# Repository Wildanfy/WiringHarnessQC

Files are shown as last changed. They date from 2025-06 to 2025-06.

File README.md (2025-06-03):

**README.md**

---

## QC Cable Tester Berbasis ESP32 + Bluetooth

**Deskripsi Singkat**
Proyek ini adalah implementasi sistem Quality Control (QC) untuk pengujian konektivitas kabel, menggunakan modul ESP32, rangkaian shift register 80/88-bit, multiplexer (MUX) hingga 6 buah, dan koneksi Bluetooth. Dengan satu rangkaian, Anda dapat memeriksa hingga 76 kanal “normal” dan 8 kanal “X” secara otomatis. Hasil QC (terhubung, putus, short, salah jalur) kemudian dikirim melalui USB Serial dan Bluetooth Serial secara bersamaan dalam format teks.

---

## Daftar Isi

1. [Fitur Utama](#fitur-utama)
2. [Persyaratan Hardware](#persyaratan-hardware)
3. [Skema Pin dan Konektivitas](#skema-pin-dan-konektivitas)
4. [Persiapan Perangkat Lunak](#persiapan-perangkat-lunak)
5. [Cara Mengunggah (Upload) ke ESP32](#cara-mengunggah-upload-ke-esp32)
6. [Perintah Bluetooth / USB Serial](#perintah-bluetooth--usb-serial)
7. [Penjelasan Fungsi-Fungsi Utama](#penjelasan-fungsi-fungsi-utama)
8. [Format Output QC](#format-output-qc)

---

## Fitur Utama

* **Pengujian 76 Kanal Normal**

  * Memanfaatkan 5 buah MUX 16:1 untuk membaca kondisi setiap pin kabel di kanal 1–76.
  * Deteksi otomatis:

    * `C` (Connected)
    * `N` (Disconnected)
    * `S&<nomor partner>` (Short dengan kanal lain)
    * `W&<nomor partner>` (Miswire / salah jalur)
  * Penanganan kondisi khusus (edge-case) pada grup K2 dan K3 sesuai skema QC kabel di dokumentasi.
* **Pengujian 8 Kanal “X” (MUX6)**

  * Rangkaian tambahan untuk kabel tipe “X” (kanal 80–87) menggunakan MUX6.
  * Deteksi antar-MUX: apabila kanal X terhubung / short / miswire ke salah satu dari 88 global bit (76 kanal normal + 8 X).
* **Bluetooth Serial + USB Serial**

  * Nama perangkat Bluetooth: **“QC Cable”**
  * Hasil pengukuran QC langsung dikirim ke kedua antarmuka (Serial USB & Bluetooth).
  * Komunikasi satu arah (ESP32 → PC / Handphone) untuk log hasil QC.
* **Mode QC Fleksibel**

  * `start` : hanya QC kabel normal (1–76)
  * `startx`: hanya QC kabel X (80–87)
  * `startall`: QC semua secara bersamaan (1–76 dan 80–87)
  * `stop` : menghentikan pengukuran QC dan mereset pin

---

## Persyaratan Hardware

1. **ESP32** (atau varian serupa dengan fitur BluetoothClassic)
2. **Shift Register 80-bit / 88-bit**

   * Anda dapat menyusun rangkaian shift register (misalnya menggunakan beberapa IC 74HC595 beruntun) untuk total 80 bit.
   * Untuk skema kabel “X” (8 kanal tambahan), gunakan shift register hingga 88 bit.
3. **Multiplexer (MUX)**

   * 5 buah MUX 16:1 (misal CD74HC4067 atau sejenis). Masing-masing MUX menangani 16 bit sinyal dari shift register untuk 76 kanal normal (5×16 = 80, gunakan 76).
   * 1 buah MUX 16:1 untuk kabel “X” (kanal 80–87).
4. **Kabel Jumper / Breadboard**
5. **Catu Daya 5V (untuk MUX & Shift Register)**
6. **Kabel Uji / Fixture**

   * Sambungkan kabel-kabel yang akan diuji ke pin output shift register / MUX sesuai diagram.
7. **Komputer / Smartphone**

   * Untuk menerima data QC via USB Serial atau Bluetooth Serial.

---

## Skema Pin dan Konektivitas

```
ESP32                              Shift Register / MUX / Fixture
--------------------------------------------------------------------------------
GPIO 23   (DS)      → Data (SER) pada shift register
GPIO 18   (SHCP)    → Clock (SRCLK) pada shift register
GPIO 5    (STCP)    → Latch (RCLK) pada shift register

GPIO 26   (SIG)     ← Output “sense” (hasil pembacaan) dari MUX (digitalRead)
GPIO 13   (S0)      → Select bit 0 pada semua MUX (S0)
GPIO 12   (S1)      → Select bit 1 pada semua MUX (S1)
GPIO 14   (S2)      → Select bit 2 pada semua MUX (S2)
GPIO 19   (S3)      → Select bit 3 pada semua MUX (S3)

GPIO 25   (EN_MUX1) → Enable MUX1 (untuk kanal 1–16)
GPIO 33   (EN_MUX2) → Enable MUX2 (untuk kanal 17–32)
GPIO 15   (EN_MUX3) → Enable MUX3 (untuk kanal 33–48)
GPIO 2    (EN_MUX4) → Enable MUX4 (untuk kanal 49–64)
GPIO 4    (EN_MUX5) → Enable MUX5 (untuk kanal 65–80)

GPIO 27   (EN_MUX6) → Enable MUX6 (untuk kabel X, kanal 80–87)
```

* **Catatan Channel Mapping**

  * Kanall 1–13 → `K1-A1` … `K1-A13`
  * Kanall 14–26 → `K1-B1` … `K1-B13`
  * Kanall 27–39 → `K2-A1` … `K2-A13`
  * Kanall 40–52 → `K2-B1` … `K2-B13`
  * Kanall 53–64 → `K3-A1` … `K3-A12`
  * Kanall 65–76 → `K3-B1` … `K3-B12`
  * Kabel “X” (8 kanal) → `X-1` … `X-8`

---

## Persiapan Perangkat Lunak

1. **Install Arduino IDE (versi terbaru disarankan)**

   * Bisa diunduh di [https://www.arduino.cc/en/software](https://www.arduino.cc/en/software) (sesuaikan OS)
2. **Tambahkan Board ESP32 ke Arduino IDE**

   * Buka **File → Preferences**
   * Tambahkan URL berikut ke `Additional Boards Manager URLs`:

     ```
     https://raw.githubusercontent.com/espressif/arduino-esp32/gh-pages/package_esp32_index.json
     ```
   * Buka **Tools → Board → Boards Manager**, cari “esp32” lalu install “esp32 by Espressif Systems”.
3. **Library yang Diperlukan**

   * `BluetoothSerial.h` (sudah tersedia saat menginstal board ESP32)
   * Tidak ada library eksternal lain (semua fungsi shift register dan multiplexer ditulis manual).

---

## Cara Mengunggah (Upload) ke ESP32

1. Sambungkan ESP32 ke komputer via kabel USB.
2. Pastikan di **Tools → Board** sudah terbaca **“ESP32 Dev Module”** (atau tipe ESP32 yang Anda gunakan).
3. Pilih **Port** yang sesuai (Tools → Port).
4. Buka file `QC_Cable.ino` (atau ganti nama menjadi `QC_Cable.ino`) pada Arduino IDE.
5. Tekan tombol **Upload** (ikon panah kanan). Tunggu hingga proses selesai, ESP32 otomatis restart.

---

## Perintah Bluetooth / USB Serial

Setelah kode berhasil berjalan, ESP32 akan menunggu perintah via USB Serial (baud rate 115200) ataupun Bluetooth Serial (“QC Cable”).
Ketik salah satu perintah berikut (tanpa tanda kutip) lalu tekan **Enter**:

* `start`

  * Menjalankan QC hanya untuk **kanal normal** (1–76).
* `startx`

  * Menjalankan QC hanya untuk **kanal “X”** (80–87).
* `startall`

  * Menjalankan QC untuk **semua kanal** (1–76 dan 80–87).
* `stop`

  * Menghentikan QC, mereset pin, dan berhenti mengirim data.

**Contoh penggunaan di Serial Monitor:**

```
> startall
```

ESP32 akan mengirimkan hasil QC berulang setiap interval 10 ms ke Serial/BT.

---

## Penjelasan Fungsi-Fungsi Utama

1. **`resetPins()`**

   * Mengatur semua pin ESP32 (DS, SHCP, STCP, SIG, S0–S3, EN\_MUX1–EN\_MUX6) ke `OUTPUT` atau `INPUT_PULLDOWN` sesuai fungsinya.
   * Memastikan initial state: latch low, clock low, data low, MUX6 (EN\_MUX6) di-`HIGH` (non-aktif).

2. **`shiftOut80(uint64_t data)`**

   * Mengirim 76 bit (dipadatkan menjadi 80 bit) ke rangkaian shift register secara paling signifikan (MSB) terlebih dahulu.
   * `data` berupa `uint64_t` dimana bit ke-0 (LSB) → kanal terakhir (nomor 75).

3. **`readMux16(int muxNumber)`**

   * Membaca 16 bit data dari MUX tertentu (1–5) dengan mengaktifkan satu `EN_MUXx` pada `LOW` dan membaca pin SIG pada setiap kombinasi `S0–S3`.
   * Mengembalikan `uint16_t` yang menandakan status HIGH/LOW pada 16 output MUX.

4. **`readAllMux(bool globalMap[], int maxCh)`**

   * Membaca MUX1–5 sekaligus, memasukkan hasilnya ke array `globalMap[]` (panjang minimal `maxCh`).
   * Hanya mengisi hingga indeks `maxCh−1`.

5. **`runQC_K1(String &outputBuffer)`**, **`runQC_K2(...)`**, **`runQC_K3(...)`**

   * Masing-masing menangani QC pada grup kabel:

     * **K1** = kanal global 0–25 (K1-A1..K1-A13, K1-B1..K1-B13)
     * **K2** = kanal global 26–51 (K2-A1..K2-A13, K2-B1..K2-B13)
     * **K3** = kanal global 52–75 (K3-A1..K3-A12, K3-B1..K3-B12)
   * Setiap fungsi:

     1. **Inisialisasi** array `ChannelResult results[...]` (state & partner).
     2. Untuk tiap channel `ch` di kelompoknya:

        * Jika `channelUsed[ch]` = `false`, tandai state = −1 (skip).
        * Lakukan `shiftOut80(1ULL << ch)`, delay, `readAllMux(...)` ke `globalMap[]`.
        * Hitung `totalActive` dalam kelompok tersebut.
        * Tentukan `state` (CONNECTED, SHORT, MISWIRE, DISCONNECTED) dan `partner` (jika SHORT/MISWIRE).
        * Penanganan **kondisi khusus**:

          * **K2**

            * Jika B2 (index internal 10) short ke B13 (index internal 25), dan B13 dianggap putus, tandai kedua channel sebagai CONNECTED.
          * **K3**

            * Jika A5 (index internal 4) putus, dan B1 (index internal 12) short ke A5, tandai keduanya sebagai CONNECTED.
     3. **Cetak hasil**: untuk tiap channel, bentuk string `"Label:State,"` (contoh: `K1-A1:C,` atau `K2-B5:W&B12,`). Tambahkan ke `outputBuffer`.

6. **`shiftOut88(uint8_t data[11])`**

   * Serupa `shiftOut80`, tetapi menggunakan array 11 byte untuk total 88 bit (1 bit extra).

7. **`readMux16X()`**

   * Membaca MUX6 (kanal X) dengan mengaktifkan `EN_MUX6 = LOW` dan membaca 16 bit, meski kanal X hanya 8 bit (bit 0–7).

8. **`runQCX(String &outputBuffer)`**

   * Menangani QC untuk 8 kanal X (global bit 80–87).
   * Algoritmanya mirip `runQC_K*`, tetapi mencakup pembacaan **seluruh 88 bit** (MUX1–5 + MUX6) untuk deteksi antar-MUX.
   * Hasil (“X-1\:C,” atau “X-3\:S\&K2-A5,” dst.) ditambahkan ke `outputBuffer`.

9. **`setup()`**

   * Inisialisasi pin dan `Serial.begin(115200)`, `SerialBT.begin("QC Cable")`.
   * `delay(1000)` singkat agar Bluetooth siap.

10. **`loop()`**

    * Terus-menerus:

      * Baca karakter dari `Serial` (USB) & `SerialBT` (Bluetooth), kumpulkan ke `bufUSB` / `bufBT`.
      * Jika ditemukan substring:

        * `"startall"`, `"startx"`, `"start"`, `"stop"` → setel `qcRunning`, `qcActive`, `qcActiveX`, `qcAllActive` sesuai mode.
      * Jika `qcRunning == true` dan interval (10 ms) tercapai:

        * Panggil `runQC_K1()`, `runQC_K2()`, `runQC_K3()` apabila mode `qcActive`/`qcAllActive`.
        * Panggil `runQCX()` apabila mode `qcActiveX`/`qcAllActive`.
        * Kirim `out` (`String` hasil QC) melalui `Serial.println(out)` dan `SerialBT.println(out)`.

---

## Format Output QC

Hasil QC dikomunikasikan dalam satu baris teks, misalnya:

```
K1-A1:C,K1-A2:N,K1-A3:S&K1-B5,...,K3-B12:W&K3-A8,X-1:C,X-2:N,X-3:S&K2-B4,...
```

* **Format umum per-kanal:**

  ```
  <Label>:<State>[&<LabelPartner>],
  ```

  * `<Label>`

    * Contoh: `K1-A1`, `K2-B7`, `K3-A12`, `X-5`
  * `<State>`

    * `C` = Connected (terhubung sempurna satu-ke-satu)
    * `N` = Disconnected (putus, tidak terdeteksi sama sekali)
    * `S&<LabelPartner>` = Short (terhubung dengan lebih dari satu bit; partner ditunjukkan)
    * `W&<LabelPartner>` = Miswire (sinyal keluar dari kelompok yang diharapkan)
  * `<LabelPartner>`

    * Menunjukkan label kanal lain yang terhubung / short / miswire. Pada `S&`/`W&`, `LabelPartner` hanya substring setelah tanda “-” (misal `B5`, `A12`).

**Contoh Lengkap**

```
K1-A1:C,K1-A2:N,K1-A3:S&K1-B5,K1-A4:W&K2-A1,...,K3-B12:C,X-1:N,X-2:C,X-3:S&K1-A7,...
```

---

### Catatan Tambahan

* Pastikan bahwa **`channelUsed[]`** diinisialisasi sesuai kebutuhan. Nilai `false` akan menyebabkan pemrosesan kanal tersebut di-skip. Anda dapat menonaktifkan atau mengaktifkan kanal tertentu dengan mengubah array `channelUsed[76]` pada baris awal kode.
* Jika Anda ingin menyesuaikan interval QC (delay antara iterasi), ubah konstanta `const unsigned long qcInterval = 10;` (nilai dalam milidetik).
* Penanganan edge-case untuk K2 dan K3 ditujukan untuk kondisi khusus kabel tertentu (misal susunan “B2 short ke B13” atau “A5 disconnected & B1 short ke A5”). Silakan sesuaikan logika ini jika topologi kabel Anda berbeda.

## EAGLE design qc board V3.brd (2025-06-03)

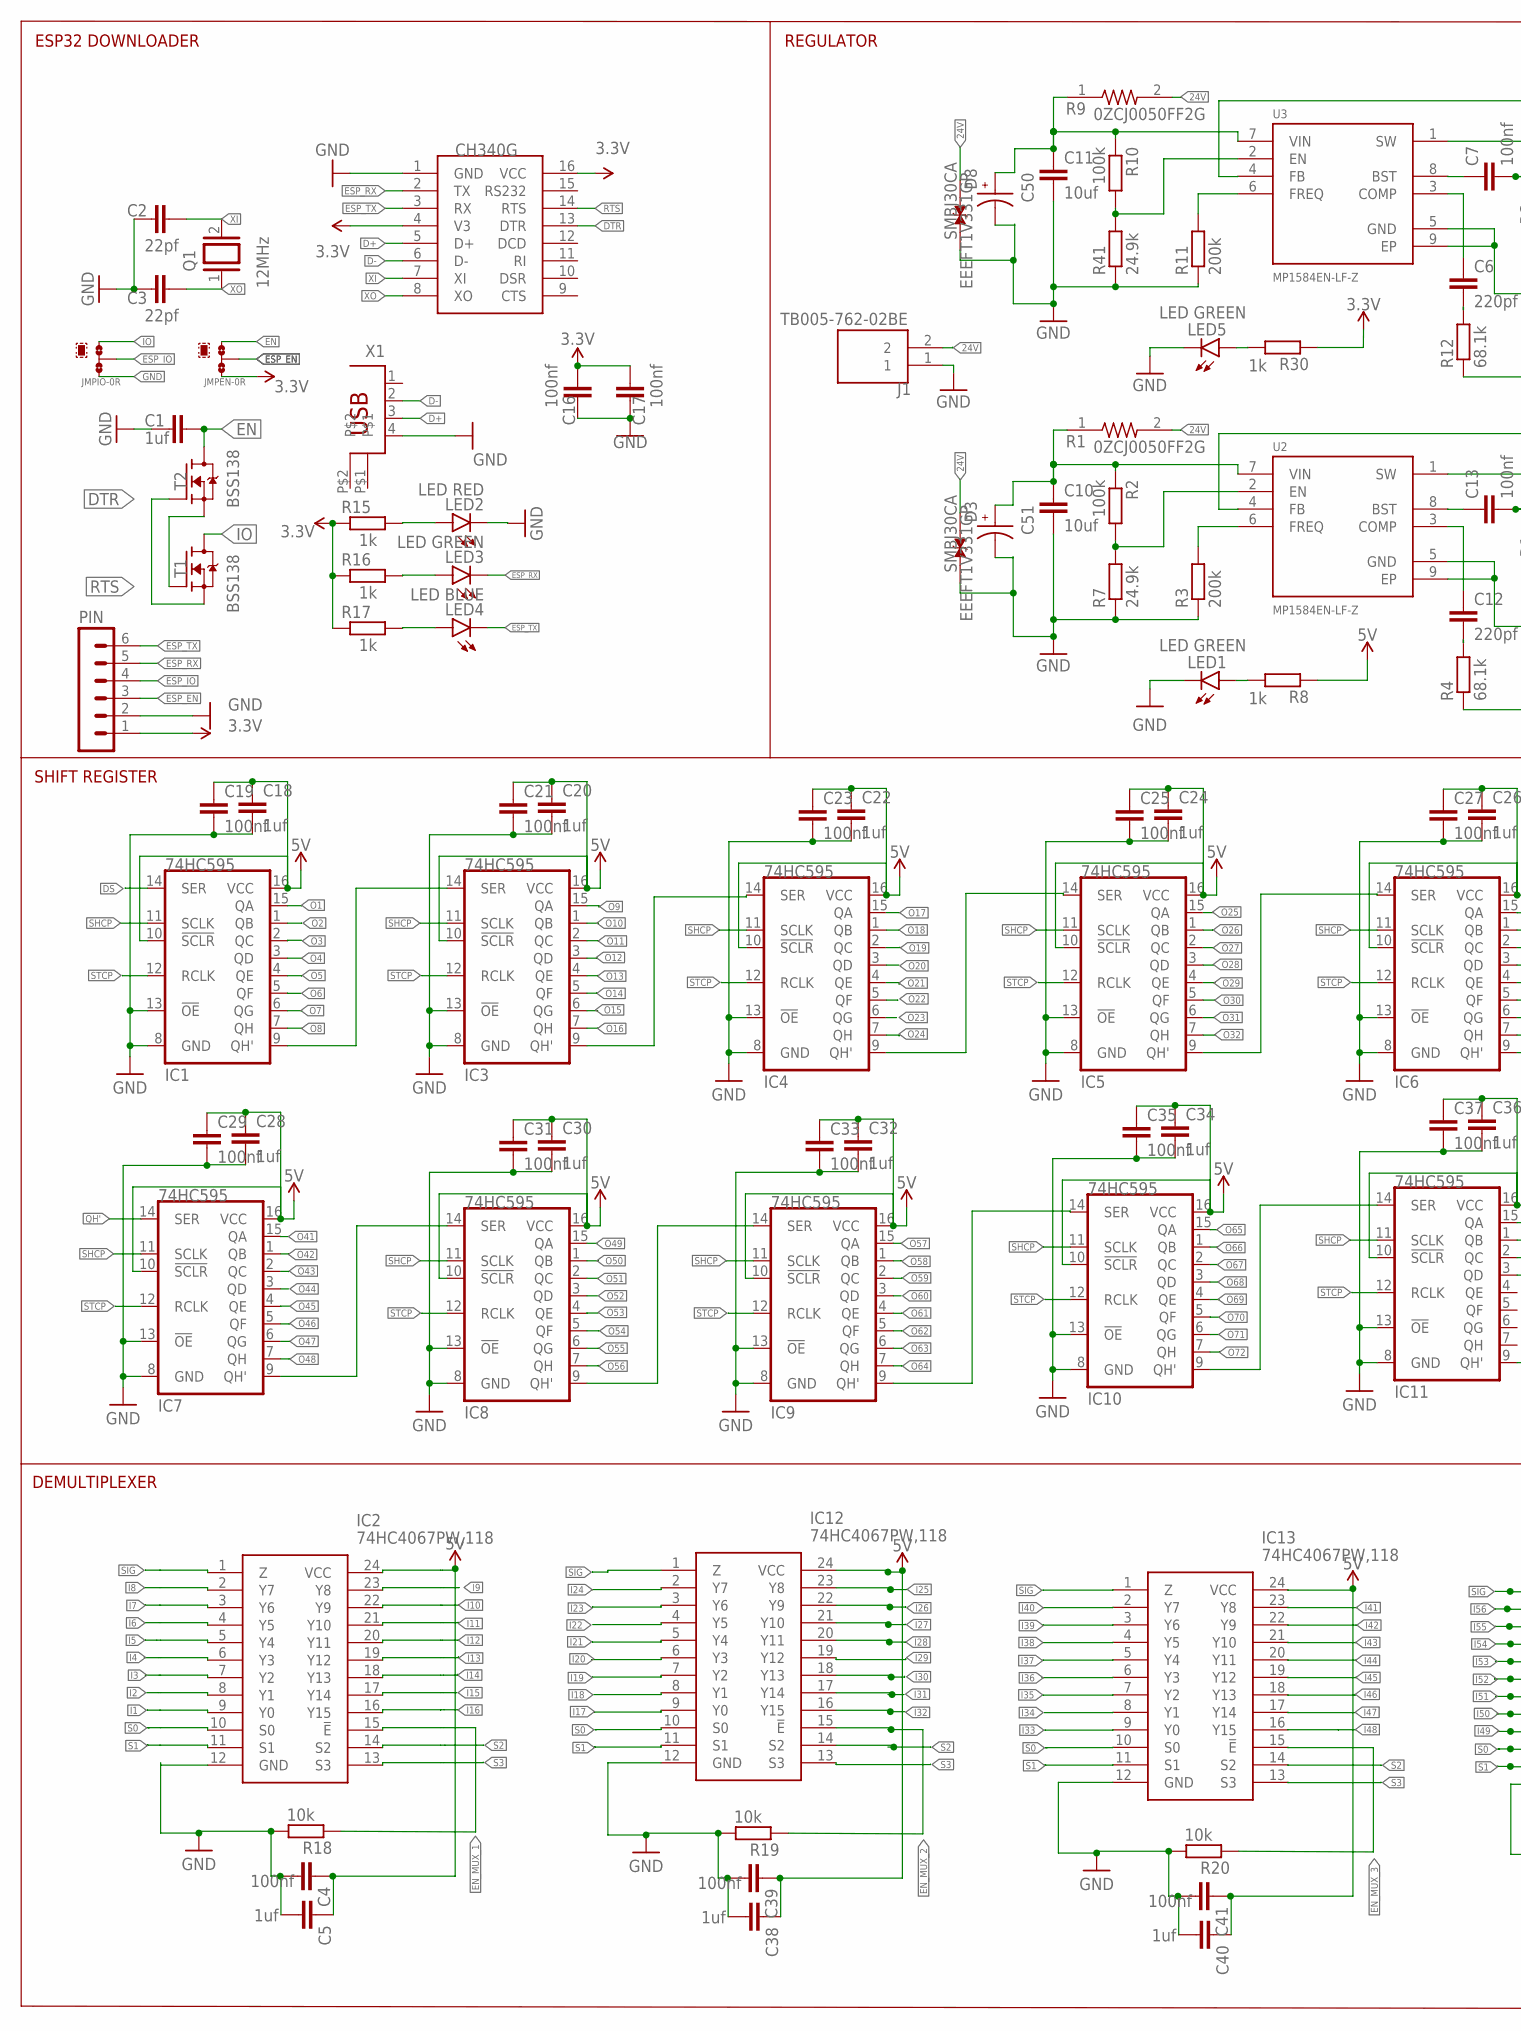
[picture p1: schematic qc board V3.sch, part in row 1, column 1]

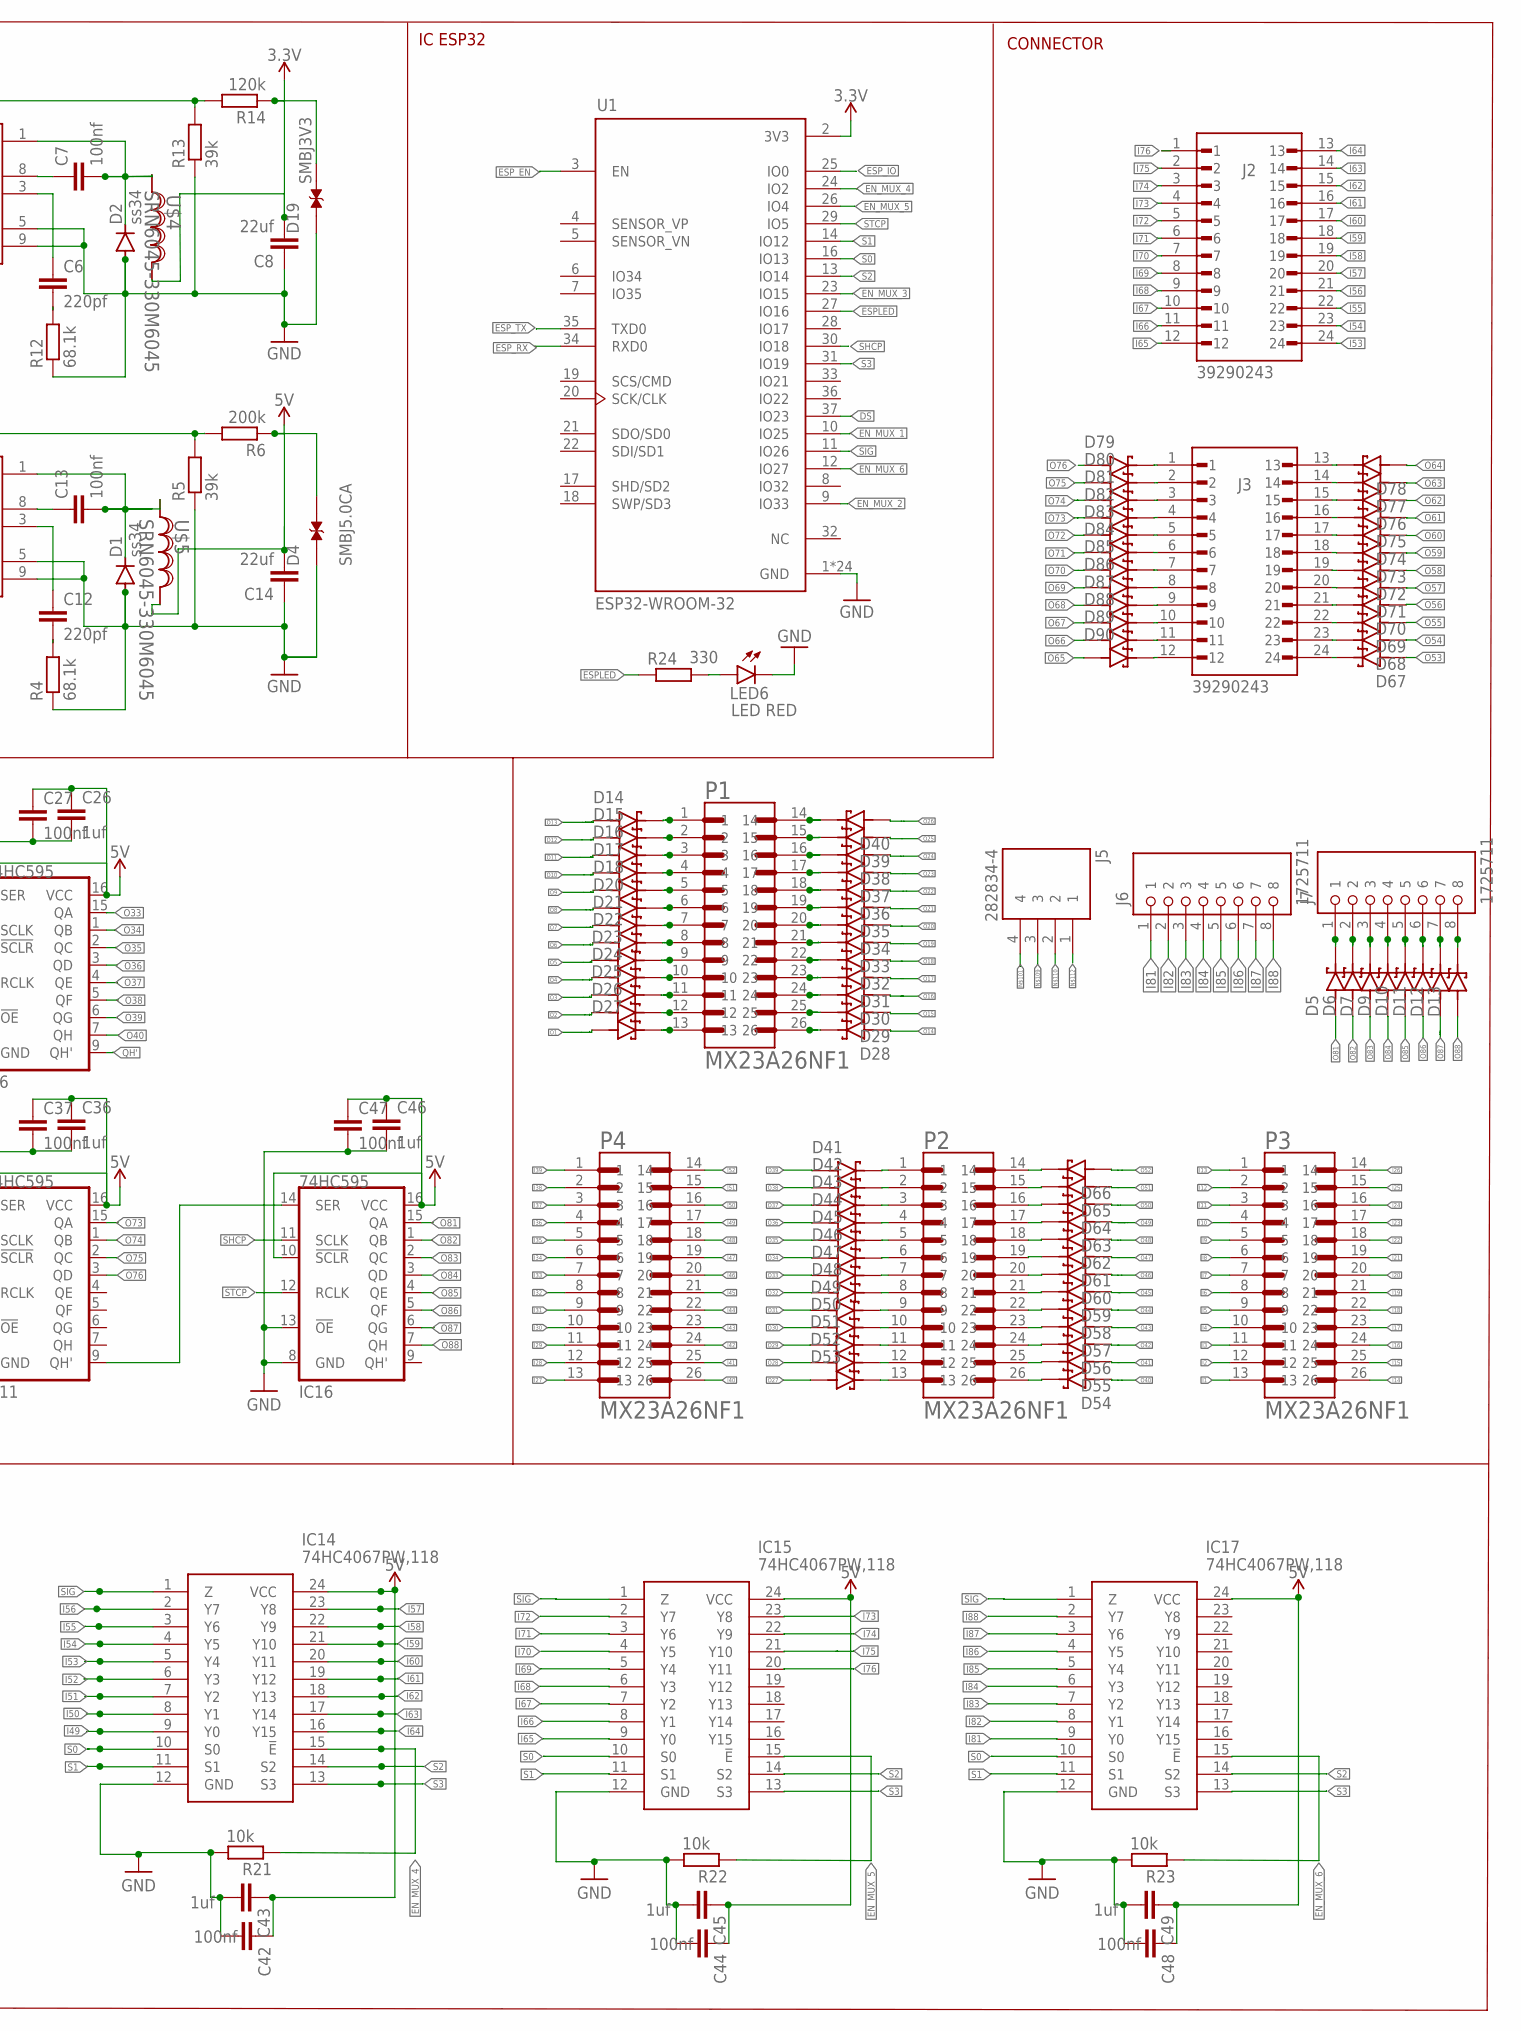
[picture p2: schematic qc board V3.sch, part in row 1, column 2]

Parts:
C1, C5, C18, C20, C22, C24, C26, C28, C30, C32, C34, C36, C38, C40, C43, C45, C46, C49: 1uf; C0805
C2, C3: 22pf; C0805
C4, C7, C13, C16, C17, C19, C21, C23, C25, C27, C29, C31, C33, C35, C37, C39, C41, C42, C44, C47, C48: 100nf; C0805
C6, C12: 220pf; C0805
C8, C14: 22uf; C0805
C10, C11: 10uf; C0805
C50, C51: EEEFT1V331GP; CAP_EEEFT1V331GP
D1, D2: ss34; SMB
D3, D8: SMBJ30CA; DIOM4336X265N
D4: SMBJ5.0CA; DIOM4336X265N
D5, D6, D7, D9, D10, D11, D12, D13, D14, D15, D16, D17, D18, D20, D21, D22, D23, D24, D25, D26, D27, D28, D29, D30, D31, D32, D33, D34, D35, D36, D37, D38, D39, D40, D41, D42, D43, D44, D45, D46, D47, D48, D49, D50, D51, D52, D53, D54, D55, D56, D57, D58, D59, D60, D61, D62, D63, D64, D65, D66, D67, D68, D69, D70, D71, D72, D73, D74, D75, D76, D77, D78, D79, D80, D81, D82, D83, D84, D85, D86, D87, D88, D89, D90: 1N5819HW-7; SOD3715X145N
D19: SMBJ3V3; DIOM4336X265N
IC1, IC3, IC4, IC5, IC6, IC7, IC8, IC9, IC10, IC11, IC16: 74HC595; SO16
IC2, IC12, IC13, IC14, IC15, IC17: 74HC4067PW,118; SOP65P640X110-24N
J1: TB005-762-02BE; CUI_TB005-762-02BE
J2, J3: 39290243; MOLEX_39290243
J5: 282834-4; TE_282834-4
J6, J7: 1725711; PHOENIX_1725711
JMPEN: 0R-JUMPB; B0R-JMP
JMPIO: 0R-JUMPB; B0R-JMP
LED1, LED5: LED GREEN; CHIP-LED0805
LED2: LED RED; CHIPLED_0805
LED3: LED GREEN; CHIPLED_0805
LED4: LED BLUE; CHIPLED_0805
LED6: LED RED; CHIP-LED0805
P1, P2, P3, P4: MX23A26NF1; JAE_MX23A26NF1
PIN: MA06-1
Q1: 12MHz; QS
R1, R9: 0ZCJ0050FF2G; RESC3216X125N
R2, R10: 100k; R0805
R3, R6, R11: 200k; R0805
R4, R12: 68.1k; R0805
R5, R13: 39k; R0805
R7, R41: 24.9k; R0805
R8, R30: 1k; R0805
R14: 120k; R0805
R15, R16, R17: 1k; M0805
R18, R19, R20, R21, R22, R23: 10k; M0805
R24: 330; R0805
T1, T2: BSS138; SOT95P240X111-3N
U1: ESP32-WROOM-32; MODULE_ESP32-WROOM-32
U2, U3: MP1584EN-LF-Z; SOIC127P600X170-9N
U$3: CH340G; SOIC16
U$4, U$5: SRN6045-330M6045; SRN6045
X1: PN61729

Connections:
3.3V: C8.2, C16.1, C17.1, D19.2, JMPEN.3, PIN.1, R14.1, R15.1, R16.1, R17.1, R30.1, U1.2 (3V3), U$3.4 (V3), U$3.16 (VCC), U$4.1
5V: C4.1, C5.1, C14.2, C18.1, C19.1, C20.1, C21.1, C22.1, C23.1, C24.1, C25.1, C26.1, C27.1, C28.1, C29.1, C30.1, C31.1, C32.1, C33.1, C34.1, C35.1, C36.1, C37.1, C38.1, C39.1, C40.1, C41.1, C42.1, C43.1, C44.1, C45.1, C46.1, C47.1, C48.1, C49.1, D4.2, IC1.10 (!SCLR), IC1.16 (VCC), IC2.24 (VCC), IC3.10 (!SCLR), IC3.16 (VCC), IC4.10 (!SCLR), IC4.16 (VCC), IC5.10 (!SCLR), IC5.16 (VCC), IC6.10 (!SCLR), IC6.16 (VCC), IC7.10 (!SCLR), IC7.16 (VCC), IC8.10 (!SCLR), IC8.16 (VCC), IC9.10 (!SCLR), IC9.16 (VCC), IC10.10 (!SCLR), IC10.16 (VCC), IC11.10 (!SCLR), IC11.16 (VCC), IC12.24 (VCC), IC13.24 (VCC), IC14.24 (VCC), IC15.24 (VCC), IC16.10 (!SCLR), IC16.16 (VCC), IC17.24 (VCC), R6.1, R8.1, U$5.1
24V: D3.1, D8.1, J1.2, R1.2, R9.2
D+: U$3.5 (D+), X1.3
D-: U$3.6 (D-), X1.2
DS: IC1.14 (SER), U1.37 (IO23)
DTR: T1.2 (S), T2.1 (G), U$3.13 (DTR)
EN: C1.1, JMPEN.1, T2.3 (D)
EN_MUX_1: IC2.15 (!E), R18.1, U1.10 (IO25)
EN_MUX_2: IC12.15 (!E), R19.1, U1.9 (IO33)
EN_MUX_3: IC13.15 (!E), R20.1, U1.23 (IO15)
EN_MUX_4: IC14.15 (!E), R21.1, U1.24 (IO2)
EN_MUX_5: IC15.15 (!E), R22.1, U1.26 (IO4)
EN_MUX_6: IC17.15 (!E), R23.1, U1.12 (IO27)
ESPLED: R24.1, U1.27 (IO16)
ESP_EN: JMPEN.2, PIN.3, U1.3 (EN)
ESP_IO: JMPIO.2, PIN.4, U1.25 (IO0)
ESP_RX: LED3.C, PIN.5, U1.34 (RXD0), U$3.2 (TX)
ESP_TX: LED4.C, PIN.6, U1.35 (TXD0), U$3.3 (RX)
GND: C1.2, C2.2, C3.2, C4.2, C5.2, C8.1, C10.2, C11.2, C14.1, C16.2, C17.2, C18.2, C19.2, C20.2, C21.2, C22.2, C23.2, C24.2, C25.2, C26.2, C27.2, C28.2, C29.2, C30.2, C31.2, C32.2, C33.2, C34.2, C35.2, C36.2, C37.2, C38.2, C39.2, C40.2, C41.2, C42.2, C43.2, C44.2, C45.2, C46.2, C47.2, C48.2, C49.2, C50.2, C51.2, D1.A, D2.A, D3.2, D4.1, D8.2, D19.1, IC1.8 (GND), IC1.13 (!OE), IC2.12 (GND), IC3.8 (GND), IC3.13 (!OE), IC4.8 (GND), IC4.13 (!OE), IC5.8 (GND), IC5.13 (!OE), IC6.8 (GND), IC6.13 (!OE), IC7.8 (GND), IC7.13 (!OE), IC8.8 (GND), IC8.13 (!OE), IC9.8 (GND), IC9.13 (!OE), IC10.8 (GND), IC10.13 (!OE), IC11.8 (GND), IC11.13 (!OE), IC12.12 (GND), IC13.12 (GND), IC14.12 (GND), IC15.12 (GND), IC16.8 (GND), IC16.13 (!OE), IC17.12 (GND), J1.1, JMPIO.3, LED1.C, LED2.C, LED5.C, LED6.C, PIN.2, R3.1, R4.1, R5.1, R7.1, R11.1, R12.1, R13.1, R18.2, R19.2, R20.2, R21.2, R22.2, R23.2, R41.1, U1.1 (GND), U1.15 (GND), U1.38 (GND), U1.39_1 (GND), U1.39_2 (GND), U1.39_3 (GND), U1.39_4 (GND), U1.39_5 (GND), U1.39_6 (GND), U1.39_7 (GND), U1.39_8 (GND), U1.39_9 (GND), U1.39_10 (GND), U1.39_11 (GND), U1.39_12 (GND), U1.39_13 (GND), U1.39_14 (GND), U1.39_15 (GND), U1.39_16 (GND), U1.39_17 (GND), U1.39_18 (GND), U1.39_19 (GND), U1.39_20 (GND), U1.39_21 (GND), U2.5 (GND), U2.9 (EP), U3.5 (GND), U3.9 (EP), U$3.1 (GND), X1.4
I1: IC2.9 (Y0), P3.13
I2: IC2.8 (Y1), P3.12
I3: IC2.7 (Y2), P3.11
I4: IC2.6 (Y3), P3.10
I5: IC2.5 (Y4), P3.9
I6: IC2.4 (Y5), P3.8
I7: IC2.3 (Y6), P3.7
I8: IC2.2 (Y7), P3.6
I9: IC2.23 (Y8), P3.5
I10: IC2.22 (Y9), P3.4
I11: IC2.21 (Y10), P3.3
I12: IC2.20 (Y11), P3.2
I13: IC2.19 (Y12), P3.1
I14: IC2.18 (Y13), P3.26
I15: IC2.17 (Y14), P3.25
I16: IC2.16 (Y15), P3.24
I17: IC12.9 (Y0), P3.23
I18: IC12.8 (Y1), P3.22
I19: IC12.7 (Y2), P3.21
I20: IC12.6 (Y3), P3.20
I21: IC12.5 (Y4), P3.19
I22: IC12.4 (Y5), P3.18
I23: IC12.3 (Y6), P3.17
I24: IC12.2 (Y7), P3.16
I25: IC12.23 (Y8), P3.15
I26: IC12.22 (Y9), P3.14
I27: IC12.21 (Y10), P4.13
I28: IC12.20 (Y11), P4.12
I29: IC12.19 (Y12), P4.11
I30: IC12.18 (Y13), P4.10
I31: IC12.17 (Y14), P4.9
I32: IC12.16 (Y15), P4.8
I33: IC13.9 (Y0), P4.7
I34: IC13.8 (Y1), P4.6
I35: IC13.7 (Y2), P4.5
I36: IC13.6 (Y3), P4.4
I37: IC13.5 (Y4), P4.3
I38: IC13.4 (Y5), P4.2
I39: IC13.3 (Y6), P4.1
I40: IC13.2 (Y7), P4.26
I41: IC13.23 (Y8), P4.25
I42: IC13.22 (Y9), P4.24
I43: IC13.21 (Y10), P4.23
I44: IC13.20 (Y11), P4.22
I45: IC13.19 (Y12), P4.21
I46: IC13.18 (Y13), P4.20
I47: IC13.17 (Y14), P4.19
I48: IC13.16 (Y15), P4.18
I49: IC14.9 (Y0), P4.17
I50: IC14.8 (Y1), P4.16
I51: IC14.7 (Y2), P4.15
I52: IC14.6 (Y3), P4.14
I53: IC14.5 (Y4), J2.24
I54: IC14.4 (Y5), J2.23
I55: IC14.3 (Y6), J2.22
I56: IC14.2 (Y7), J2.21
I57: IC14.23 (Y8), J2.20
I58: IC14.22 (Y9), J2.19
I59: IC14.21 (Y10), J2.18
I60: IC14.20 (Y11), J2.17
I61: IC14.19 (Y12), J2.16
I62: IC14.18 (Y13), J2.15
I63: IC14.17 (Y14), J2.14
I64: IC14.16 (Y15), J2.13
I65: IC15.9 (Y0), J2.12
I66: IC15.8 (Y1), J2.11
I67: IC15.7 (Y2), J2.10
I68: IC15.6 (Y3), J2.9
I69: IC15.5 (Y4), J2.8
I70: IC15.4 (Y5), J2.7
I71: IC15.3 (Y6), J2.6
I72: IC15.2 (Y7), J2.5
I73: IC15.23 (Y8), J2.4
I74: IC15.22 (Y9), J2.3
I75: IC15.21 (Y10), J2.2
I76: IC15.20 (Y11), J2.1
I81: IC17.9 (Y0), J6.1
I82: IC17.8 (Y1), J6.2
I83: IC17.7 (Y2), J6.3
I84: IC17.6 (Y3), J6.4
I85: IC17.5 (Y4), J6.5
I86: IC17.4 (Y5), J6.6
I87: IC17.3 (Y6), J6.7
I88: IC17.2 (Y7), J6.8
IO: JMPIO.1, T1.3 (D)
unnamed: R10.2, R41.2, U3.2 (EN)
unnamed: R3.2, U2.6 (FREQ)
unnamed: R11.2, U3.6 (FREQ)
unnamed: C7.1, U3.8 (BST)
unnamed: C7.2, D2.C, U3.1 (SW), U$4.2
unnamed: C13.1, U2.8 (BST)
unnamed: C6.2, R12.2
unnamed: C6.1, U3.3 (COMP)
unnamed: LED5.A, R30.2
unnamed: R13.2, R14.2, U3.4 (FB)
unnamed: C13.2, D1.C, U2.1 (SW), U$5.2
unnamed: R5.2, R6.2, U2.4 (FB)
unnamed: C12.2, R4.2
unnamed: R2.2, R7.2, U2.2 (EN)
unnamed: C12.1, U2.3 (COMP)
unnamed: LED1.A, R8.2
unnamed: LED2.A, R15.2
unnamed: LED3.A, R16.2
unnamed: LED4.A, R17.2
unnamed: IC11.9 (QH'), IC16.14 (SER)
unnamed: D5.C (K), J7.1
unnamed: D6.C (K), J7.2
unnamed: D7.C (K), J7.3
unnamed: D9.C (K), J7.4
unnamed: D10.C (K), J7.5
unnamed: D11.C (K), J7.6
unnamed: D12.C (K), J7.7
unnamed: IC1.9 (QH'), IC3.14 (SER)
unnamed: IC3.9 (QH'), IC4.14 (SER)
unnamed: IC4.9 (QH'), IC5.14 (SER)
unnamed: IC5.9 (QH'), IC6.14 (SER)
unnamed: IC7.9 (QH'), IC8.14 (SER)
unnamed: IC8.9 (QH'), IC9.14 (SER)
unnamed: IC9.9 (QH'), IC10.14 (SER)
unnamed: IC10.9 (QH'), IC11.14 (SER)
unnamed: D13.C (K), J7.8
unnamed: D14.C (K), P1.1
unnamed: D15.C (K), P1.2
unnamed: D16.C (K), P1.3
unnamed: D17.C (K), P1.4
unnamed: D18.C (K), P1.5
unnamed: D20.C (K), P1.6
unnamed: D21.C (K), P1.7
unnamed: D22.C (K), P1.8
unnamed: D23.C (K), P1.9
unnamed: D24.C (K), P1.10
unnamed: D25.C (K), P1.11
unnamed: D26.C (K), P1.12
unnamed: D27.C (K), P1.13
unnamed: D40.C (K), P1.14
unnamed: D39.C (K), P1.15
unnamed: D38.C (K), P1.16
unnamed: D37.C (K), P1.17
unnamed: D36.C (K), P1.18
unnamed: D35.C (K), P1.19
unnamed: D34.C (K), P1.20
unnamed: D33.C (K), P1.21
unnamed: D32.C (K), P1.22
unnamed: D31.C (K), P1.23
unnamed: D30.C (K), P1.24
unnamed: D29.C (K), P1.25
unnamed: D28.C (K), P1.26
unnamed: D41.C (K), P2.1
unnamed: D42.C (K), P2.2
unnamed: D43.C (K), P2.3
unnamed: D44.C (K), P2.4
unnamed: D45.C (K), P2.5
unnamed: D46.C (K), P2.6
unnamed: D47.C (K), P2.7
unnamed: D48.C (K), P2.8
unnamed: D49.C (K), P2.9
unnamed: D50.C (K), P2.10
unnamed: D51.C (K), P2.11
unnamed: D52.C (K), P2.12
unnamed: D53.C (K), P2.13
unnamed: D69.C (K), J3.22
unnamed: D68.C (K), J3.23
unnamed: D66.C (K), P2.14
unnamed: D65.C (K), P2.15
unnamed: D64.C (K), P2.16
unnamed: D63.C (K), P2.17
unnamed: D62.C (K), P2.18
unnamed: D61.C (K), P2.19
unnamed: D60.C (K), P2.20
unnamed: D59.C (K), P2.21
unnamed: D58.C (K), P2.22
unnamed: D57.C (K), P2.23
unnamed: D56.C (K), P2.24
unnamed: D55.C (K), P2.25
unnamed: D54.C (K), P2.26
unnamed: D67.C (K), J3.24
unnamed: D70.C (K), J3.21
unnamed: D78.C (K), J3.13
unnamed: D77.C (K), J3.14
unnamed: D76.C (K), J3.15
unnamed: D75.C (K), J3.16
unnamed: D74.C (K), J3.17
unnamed: D73.C (K), J3.18
unnamed: D72.C (K), J3.19, J5.4
unnamed: D71.C (K), J3.20
unnamed: D79.C (K), J3.1
unnamed: D80.C (K), J3.2
unnamed: D81.C (K), J3.3
unnamed: D82.C (K), J3.4
unnamed: D83.C (K), J3.5
unnamed: D84.C (K), J3.6
unnamed: D85.C (K), J3.7, J5.3
unnamed: D86.C (K), J3.8, J5.2
unnamed: D87.C (K), J3.9
unnamed: D88.C (K), J3.10, J5.1
unnamed: D89.C (K), J3.11
unnamed: D90.C (K), J3.12
unnamed: LED6.A, R24.2
O1: D27.A, IC1.15 (QA)
O2: D26.A, IC1.1 (QB)
O3: D25.A, IC1.2 (QC)
O4: D24.A, IC1.3 (QD)
O5: D23.A, IC1.4 (QE)
O6: D22.A, IC1.5 (QF)
O7: D21.A, IC1.6 (QG)
O8: D20.A, IC1.7 (QH)
O9: D18.A, IC3.15 (QA)
O10: D17.A, IC3.1 (QB)
O11: D16.A, IC3.2 (QC)
O12: D15.A, IC3.3 (QD)
O13: D14.A, IC3.4 (QE)
O14: D28.A, IC3.5 (QF)
O15: D29.A, IC3.6 (QG)
O16: D30.A, IC3.7 (QH)
O17: D31.A, IC4.15 (QA)
O18: D32.A, IC4.1 (QB)
O19: D33.A, IC4.2 (QC)
O20: D34.A, IC4.3 (QD)
O21: D35.A, IC4.4 (QE)
O22: D36.A, IC4.5 (QF)
O23: D37.A, IC4.6 (QG)
O24: D38.A, IC4.7 (QH)
O25: D39.A, IC5.15 (QA)
O26: D40.A, IC5.1 (QB)
O27: D53.A, IC5.2 (QC)
O28: D52.A, IC5.3 (QD)
O29: D51.A, IC5.4 (QE)
O30: D50.A, IC5.5 (QF)
O31: D49.A, IC5.6 (QG)
O32: D48.A, IC5.7 (QH)
O33: D47.A, IC6.15 (QA)
O34: D46.A, IC6.1 (QB)
O35: D45.A, IC6.2 (QC)
O36: D44.A, IC6.3 (QD)
O37: D43.A, IC6.4 (QE)
O38: D42.A, IC6.5 (QF)
O39: D41.A, IC6.6 (QG)
O40: D54.A, IC6.7 (QH)
O41: D55.A, IC7.15 (QA)
O42: D56.A, IC7.1 (QB)
O43: D57.A, IC7.2 (QC)
O44: D58.A, IC7.3 (QD)
O45: D59.A, IC7.4 (QE)
O46: D60.A, IC7.5 (QF)
O47: D61.A, IC7.6 (QG)
O48: D62.A, IC7.7 (QH)
O49: D63.A, IC8.15 (QA)
O50: D64.A, IC8.1 (QB)
O51: D65.A, IC8.2 (QC)
O52: D66.A, IC8.3 (QD)
O53: D67.A, IC8.4 (QE)
O54: D68.A, IC8.5 (QF)
O55: D69.A, IC8.6 (QG)
O56: D70.A, IC8.7 (QH)
O57: D71.A, IC9.15 (QA)
O58: D72.A, IC9.1 (QB)
O59: D73.A, IC9.2 (QC)
O60: D74.A, IC9.3 (QD)
O61: D75.A, IC9.4 (QE)
O62: D76.A, IC9.5 (QF)
O63: D77.A, IC9.6 (QG)
O64: D78.A, IC9.7 (QH)
O65: D90.A, IC10.15 (QA)
O66: D89.A, IC10.1 (QB)
O67: D88.A, IC10.2 (QC)
O68: D87.A, IC10.3 (QD)
O69: D86.A, IC10.4 (QE)
O70: D85.A, IC10.5 (QF)
O71: D84.A, IC10.6 (QG)
O72: D83.A, IC10.7 (QH)
O73: D82.A, IC11.15 (QA)
O74: D81.A, IC11.1 (QB)
O75: D80.A, IC11.2 (QC)
O76: D79.A, IC11.3 (QD)
O81: D5.A, IC16.15 (QA)
O82: D6.A, IC16.1 (QB)
O83: D7.A, IC16.2 (QC)
O84: D9.A, IC16.3 (QD)
O85: D10.A, IC16.4 (QE)
O86: D11.A, IC16.5 (QF)
O87: D12.A, IC16.6 (QG)
O88: D13.A, IC16.7 (QH)
OUT_FUSE: C11.1, C50.1, R9.1, R10.1, U3.7 (VIN)
OUT_FUSE1: C10.1, C51.1, R1.1, R2.1, U2.7 (VIN)
QH': IC6.9 (QH'), IC7.14 (SER)
RTS: T1.1 (G), T2.2 (S), U$3.14 (RTS)
S0: IC2.10 (S0), IC12.10 (S0), IC13.10 (S0), IC14.10 (S0), IC15.10 (S0), IC17.10 (S0), U1.16 (IO13)
S1: IC2.11 (S1), IC12.11 (S1), IC13.11 (S1), IC14.11 (S1), IC15.11 (S1), IC17.11 (S1), U1.14 (IO12)
S2: IC2.14 (S2), IC12.14 (S2), IC13.14 (S2), IC14.14 (S2), IC15.14 (S2), IC17.14 (S2), U1.13 (IO14)
S3: IC2.13 (S3), IC12.13 (S3), IC13.13 (S3), IC14.13 (S3), IC15.13 (S3), IC17.13 (S3), U1.31 (IO19)
SHCP: IC1.11 (SCLK), IC3.11 (SCLK), IC4.11 (SCLK), IC5.11 (SCLK), IC6.11 (SCLK), IC7.11 (SCLK), IC8.11 (SCLK), IC9.11 (SCLK), IC10.11 (SCLK), IC11.11 (SCLK), IC16.11 (SCLK), U1.30 (IO18)
SIG: IC2.1 (Z), IC12.1 (Z), IC13.1 (Z), IC14.1 (Z), IC15.1 (Z), IC17.1 (Z), U1.11 (IO26)
STCP: IC1.12 (RCLK), IC3.12 (RCLK), IC4.12 (RCLK), IC5.12 (RCLK), IC6.12 (RCLK), IC7.12 (RCLK), IC8.12 (RCLK), IC9.12 (RCLK), IC10.12 (RCLK), IC11.12 (RCLK), IC16.12 (RCLK), U1.29 (IO5)
XI: C2.1, Q1.2, U$3.7 (XI)
XO: C3.1, Q1.1, U$3.8 (XO)

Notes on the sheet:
ESP32 DOWNLOADER
REGULATOR
IC ESP32
CONNECTOR
SHIFT REGISTER
DEMULTIPLEXER

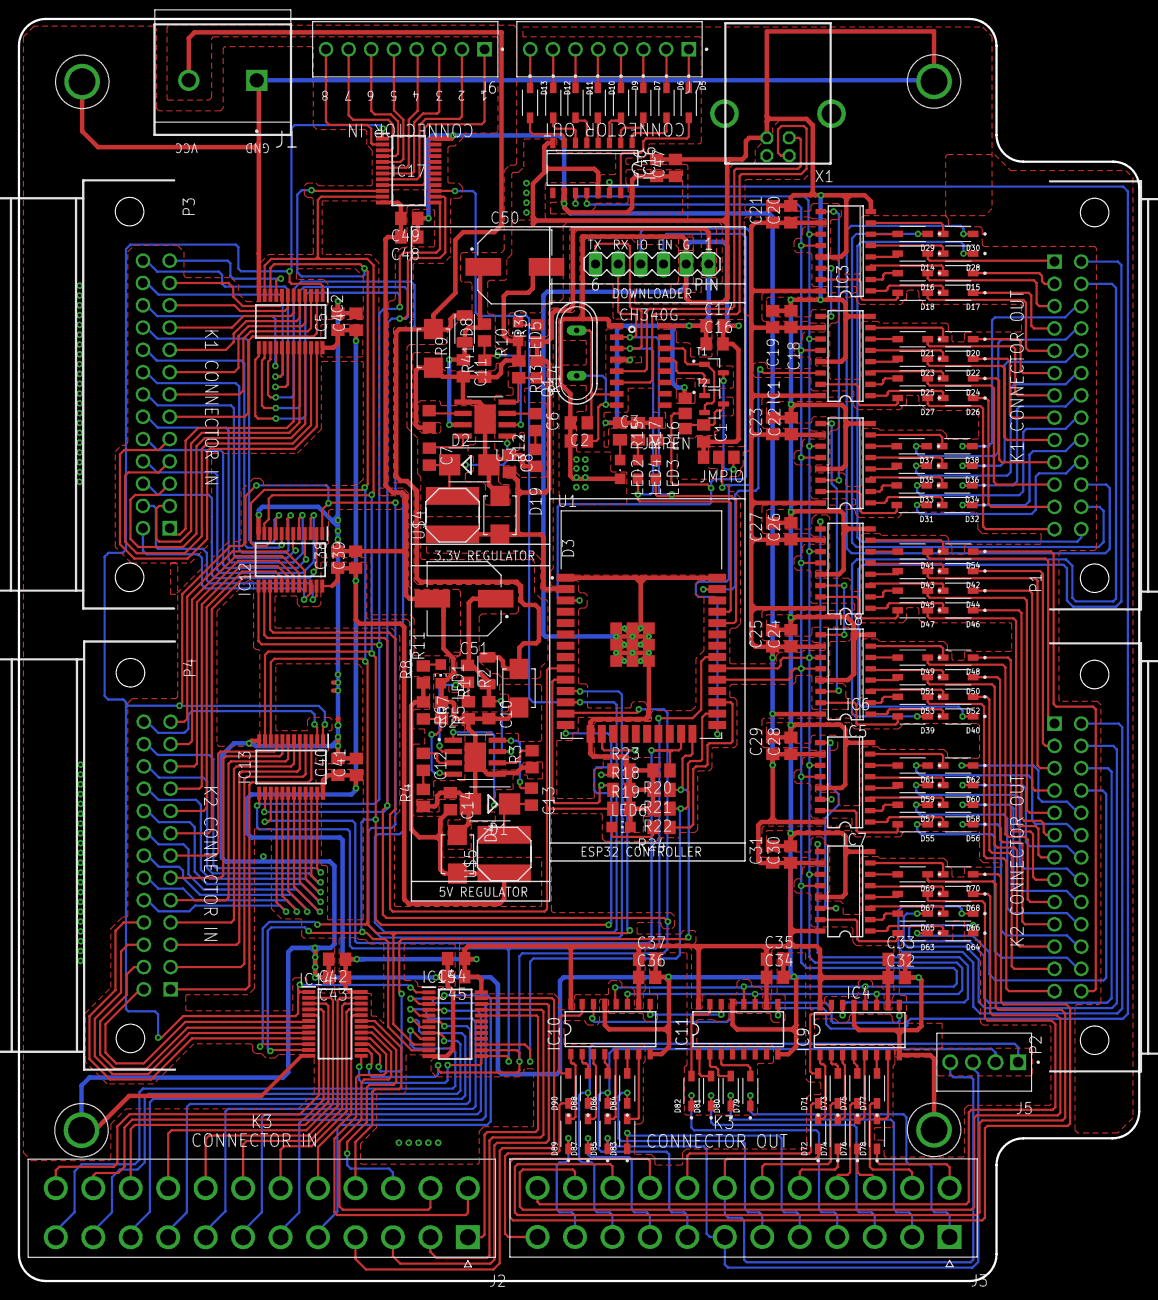
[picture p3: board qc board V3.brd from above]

Board: 2 copper layers, 125.6 x 141.5 mm, 211 parts (0 on the bottom side), 315 nets.

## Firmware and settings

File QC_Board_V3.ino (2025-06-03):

#include <BluetoothSerial.h>
BluetoothSerial SerialBT;
// struct global untuk menyimpan hasil QC satu channel
struct ChannelResult {
  int state;      // STATE_CONNECTED, STATE_DISCONNECTED, STATE_SHORT, STATE_MISWIRE
  int partner;    // channel partner untuk SHORT atau MISWIRE
};


#define DS 23    // Data (SER)
#define SHCP 18  // Clock (SRCLK)
#define STCP 5   // Latch (RCLK)

#define SIG 26   // Output dari MUX
#define S0 13    // Select pin 0
#define S1 12    // Select pin 1
#define S2 14    // Select pin 2
#define S3 19    // Select pin 3
#define EN_MUX1 25  // Enable MUX 1
#define EN_MUX2 33  // Enable MUX 2
#define EN_MUX3 15  // Enable MUX 3
#define EN_MUX4 2   // Enable MUX 4
#define EN_MUX5 4   // Enable MUX 5

// --- PENAMBAHAN UNTUK KABEL X --- //
#define EN_MUX6 27  // Enable MUX 6 (kabel X)

// Definisi status kabel
#define STATE_CONNECTED     0      // Terhubung (C)
#define STATE_DISCONNECTED  1      // Putus (N)
#define STATE_SHORT         2      // Short (S)
#define STATE_MISWIRE       3      // Salah jalur (W&...)

// Delay antar channel (ms)
const int interval = 0;

// Array status channel: true = digunakan, false = tidak digunakan
bool channelUsed[76] = {
  true, false, false, false, true, true, true, true, true, false, false, true, true,  // Channel 1-13
  false, true, false, false, false, false, false, false, true, false, true, true, false,  // Channel 14-26
  true, true, true, true, false, true, true, true, true, true, true, false, true,           // Channel 27-39
  true, true, false, true, true, true, true, false, false, true, true, false, true,           // Channel 40-52
  true, true, true, true, true, true, true, true, true, true, true, true,                   // Channel 53-64
  true, true, true, true, true, true, true, true, true, true, true, true                  // Channel 65-76
};

// Fungsi untuk menghitung jumlah bit yang aktif dalam uint16_t
uint8_t countSetBits(uint16_t value) {
  uint8_t count = 0;
  while (value) {
    count += (value & 1);
    value >>= 1;
  }
  return count;
}

// Menghasilkan label kabel berdasarkan nomor global channel
String getLabel(int globalChannel) {
  if (globalChannel <= 13) {
    return "K1-A" + String(globalChannel);
  } else if (globalChannel <= 26) {
    return "K1-B" + String(globalChannel - 13);
  } else if (globalChannel <= 39) {
    return "K2-A" + String(globalChannel - 26);
  } else if (globalChannel <= 52) {
    return "K2-B" + String(globalChannel - 39);
  } else if (globalChannel <= 64) {
    return "K3-A" + String(globalChannel - 52);
  } else {
    return "K3-B" + String(globalChannel - 64);
  }
}



void resetPins() {
  pinMode(DS, OUTPUT);
  pinMode(SHCP, OUTPUT);
  pinMode(STCP, OUTPUT);
  
  digitalWrite(DS, LOW);
  digitalWrite(SHCP, LOW);
  digitalWrite(STCP, LOW);

  pinMode(SIG, INPUT_PULLDOWN);

  pinMode(S0, OUTPUT);
  pinMode(S1, OUTPUT);
  pinMode(S2, OUTPUT);
  pinMode(S3, OUTPUT);
  
  digitalWrite(EN_MUX1, LOW);
  digitalWrite(EN_MUX2, LOW);
  digitalWrite(EN_MUX3, LOW);
  digitalWrite(EN_MUX4, LOW);
  digitalWrite(EN_MUX5, LOW);
  digitalWrite(EN_MUX6, HIGH);
}

// --- FUNGSI SHIFT REGISTER UNTUK 76 BIT --- //
void shiftOut80(uint64_t data) {
  digitalWrite(STCP, LOW);
  for (int i = 75; i >= 0; i--) {
    digitalWrite(SHCP, LOW);
    digitalWrite(DS, (data >> i) & 1);
    digitalWrite(SHCP, HIGH);
    delayMicroseconds(5);
  }
  digitalWrite(STCP, HIGH);
  delayMicroseconds(20);
}

// Membaca nilai 16-bit dari MUX (MUX 1-5)
uint16_t readMux16(int muxNumber) {
  uint16_t muxData = 0;
  
  digitalWrite(EN_MUX1, muxNumber == 1 ? LOW : HIGH);
  digitalWrite(EN_MUX2, muxNumber == 2 ? LOW : HIGH);
  digitalWrite(EN_MUX3, muxNumber == 3 ? LOW : HIGH);
  digitalWrite(EN_MUX4, muxNumber == 4 ? LOW : HIGH);
  digitalWrite(EN_MUX5, muxNumber == 5 ? LOW : HIGH);
  
  for (int i = 0; i < 16; i++) {
    digitalWrite(S0, i & 0x01);
    digitalWrite(S1, (i >> 1) & 0x01);
    digitalWrite(S2, (i >> 2) & 0x01);
    digitalWrite(S3, (i >> 3) & 0x01);
    delayMicroseconds(10);
    
    pinMode(SIG, INPUT_PULLDOWN);
    int val = digitalRead(SIG);
    if (val == HIGH) {
      muxData |= (1 << i);
    }
  }
  return muxData;
}

// Struct untuk menyimpan hasil deteksi tiap channel

// Global flag untuk mode QC kabel normal dan kabel X
bool qcActive = false;
bool qcActiveX = false;
bool qcAllActive = false;

//
// Fungsi runQC() untuk kabel normal (channel 1-76)
// tanpa iterasi sampling (mengambil pembacaan satu kali)
//
// --- FUNGSI runQC() untuk kabel normal (channel 1-76) ---
// --- NEW: read all 6 MUX outputs into one 96-bit array (we'll actually use up to 88) ---
// ===================================================
// Run full QC untuk 76 channel normal (MUX1–5),
// dengan deteksi antar-MUX
// ===================================================
// ===== Fungsi generic untuk membaca globalMap =====
void readAllMux(bool globalMap[], int maxCh) {
  // baca MUX1–5
  for (int m = 1; m <= 5; m++) {
    uint16_t d16 = readMux16(m);
    for (int b = 0; b < 16; b++) {
      int idx = (m-1)*16 + b;
      if (idx < maxCh) globalMap[idx] = (d16 >> b) & 1;
    }
  }
}

void runQC_K1(String &outputBuffer) {
  const int startCh = 0, endCh = 26; 
  ChannelResult results[26];
  bool globalMap[76] = {0};

  for (int i = startCh; i < endCh; i++) {
    results[i - startCh].state   = -1;
    results[i - startCh].partner = -1;
  }

  for (int ch = startCh; ch < endCh; ch++) {
    if (!channelUsed[ch]) {
      results[ch - startCh].state = -1; 
       yield();
      continue;
    }

    shiftOut80(1ULL << ch);
    delayMicroseconds(5);

    memset(globalMap, 0, sizeof(globalMap));
    readAllMux(globalMap, 76);

    int totalActive = 0;
    for (int i = startCh; i < endCh; i++)
      totalActive += globalMap[i];
    bool selfActive = globalMap[ch];

    // 4) Tentukan state & partner hanya dalam grup ini
    if (selfActive) {
      if (totalActive == 1) {
        results[ch - startCh].state = STATE_CONNECTED;
      } else {
        results[ch - startCh].state = STATE_SHORT;
        // cari partner dalam range startCh..endCh
        for (int i = startCh; i < endCh; i++) {
          if (i != ch && globalMap[i]) {
            results[ch - startCh].partner = i;
            break;
          }
        }
      }
    } else {
      if (totalActive > 0) {
        results[ch - startCh].state = STATE_MISWIRE;
        for (int i = startCh; i < endCh; i++) {
          if (globalMap[i]) {
            results[ch - startCh].partner = i;
            break;
          }
        }
      } else {
        results[ch - startCh].state = STATE_DISCONNECTED;
      }
    }
     yield();
  }

  // 5) Cetak hasil untuk K1 saja
  for (int i = startCh; i < endCh; i++) {
    String label = getLabel(i+1);
    String s;
    ChannelResult &r = results[i - startCh];
    switch (r.state) {
      case STATE_CONNECTED:    s = "C"; break;
      case STATE_DISCONNECTED: s = "N"; break;
      case STATE_SHORT:
        s = "S&" + getLabel(r.partner+1).substring(getLabel(r.partner+1).indexOf('-')+1);
        break;
      case STATE_MISWIRE:
        s = "W&" + getLabel(r.partner+1).substring(getLabel(r.partner+1).indexOf('-')+1);
        break;
      default: s = "E"; break;
    }
    char buf[40];
  snprintf(buf, sizeof(buf), "%s:%s,", label.c_str(), s.c_str());
    outputBuffer += buf;
      yield();
  }
}

void runQC_K2(String &outputBuffer) {
  const int startCh = 26, endCh = 52;  // global 0–25
  ChannelResult results[26];
  bool globalMap[76] = {0};

  // Inisialisasi
  for (int i = startCh; i < endCh; i++) {
    results[i - startCh].state   = -1;
    results[i - startCh].partner = -1;
  }

  for (int ch = startCh; ch < endCh; ch++) {
    if (!channelUsed[ch]) {
      results[ch - startCh].state = -1;  // skip
       yield();
      continue;
    }

    // 1) Shift sinyal di bit ch
    shiftOut80(1ULL << ch);
     yield();
    delayMicroseconds(5);

    // 2) Baca semua MUX (tapi kita akan evaluasi subset)
    memset(globalMap, 0, sizeof(globalMap));
    readAllMux(globalMap, 76);

    // 3) Hitung totalActive & selfActive DALAM rentang K1
    int totalActive = 0;
    for (int i = startCh; i < endCh; i++)
      totalActive += globalMap[i];
    bool selfActive = globalMap[ch];

    // 4) Tentukan state & partner hanya dalam grup ini
    if (selfActive) {
      if (totalActive == 1) {
        results[ch - startCh].state = STATE_CONNECTED;
      } else {
        results[ch - startCh].state = STATE_SHORT;
        // cari partner dalam range startCh..endCh
        for (int i = startCh; i < endCh; i++) {
          if (i != ch && globalMap[i]) {
            results[ch - startCh].partner = i;
            break;
          }
        }
      }
    } else {
      if (totalActive > 0) {
        results[ch - startCh].state = STATE_MISWIRE;
        for (int i = startCh; i < endCh; i++) {
          if (globalMap[i]) {
            results[ch - startCh].partner = i;
            break;
          }
        }
      } else {
        results[ch - startCh].state = STATE_DISCONNECTED;
      }
    }
  }

  {
    // Dalam array results, index 0..12 = K2-A1..K2-A13, index 13..25 = K2-B1..K2-B13
    const int idxA10  = 9;   // K2-B2  → results[14]
    const int idxB13 = 13 + (13 - 1);  // K2-B13 → results[25]

    // Cek kondisi: B2 short dengan B13, sekaligus B3 disconnected
    if ( results[idxA10].state   == STATE_SHORT
      && results[idxA10].partner == (startCh + idxB13)
      && results[idxB13].state   == STATE_DISCONNECTED
    ) {
      // Tandai B2 dan B13 sebagai connected
      results[idxA10].state   = STATE_CONNECTED;
      results[idxB13].state  = STATE_CONNECTED;
      // Hapus partner agar tidak tercetak "S&..." atau "W&..."
      results[idxA10].partner  = -1;
      results[idxB13].partner = -1;
    }
     yield();
  }

  // 5) Cetak hasil untuk K1 saja
  for (int i = startCh; i < endCh; i++) {
    String label = getLabel(i+1);
    String s;
    ChannelResult &r = results[i - startCh];
    switch (r.state) {
      case STATE_CONNECTED:    s = "C"; break;
      case STATE_DISCONNECTED: s = "N"; break;
      case STATE_SHORT:
        s = "S&" + getLabel(r.partner+1).substring(getLabel(r.partner+1).indexOf('-')+1);
        break;
      case STATE_MISWIRE:
        s = "W&" + getLabel(r.partner+1).substring(getLabel(r.partner+1).indexOf('-')+1);
        break;
      default: s = "E"; break;
    }
    char buf[40];
snprintf(buf, sizeof(buf), "%s:%s,", label.c_str(), s.c_str());
    outputBuffer += buf;
    yield();
  }
}

void runQC_K3(String &outputBuffer) {
  const int startCh = 52, endCh = 76;  
  ChannelResult results[26];
  bool globalMap[76] = {0};

  // Inisialisasi
  for (int i = startCh; i < endCh; i++) {
    results[i - startCh].state   = -1;
    results[i - startCh].partner = -1;
  }

  for (int ch = startCh; ch < endCh; ch++) {
    if (!channelUsed[ch]) {
      results[ch - startCh].state = -1;  // skip
      continue;
    }

    // 1) Shift sinyal di bit ch
    shiftOut80(1ULL << ch);
    delayMicroseconds(5);

    // 2) Baca semua MUX (tapi kita akan evaluasi subset)
    memset(globalMap, 0, sizeof(globalMap));
    readAllMux(globalMap, 76);

    // 3) Hitung totalActive & selfActive DALAM rentang K1
    int totalActive = 0;
    for (int i = startCh; i < endCh; i++)
      totalActive += globalMap[i];
    bool selfActive = globalMap[ch];

    // 4) Tentukan state & partner hanya dalam grup ini
    if (selfActive) {
      if (totalActive == 1) {
        results[ch - startCh].state = STATE_CONNECTED;
      } else {
        results[ch - startCh].state = STATE_SHORT;
        // cari partner dalam range startCh..endCh
        for (int i = startCh; i < endCh; i++) {
          if (i != ch && globalMap[i]) {
            results[ch - startCh].partner = i;
            break;
          }
        }
      }
    } else {
      if (totalActive > 0) {
        results[ch - startCh].state = STATE_MISWIRE;
        for (int i = startCh; i < endCh; i++) {
          if (globalMap[i]) {
            results[ch - startCh].partner = i;
            break;
          }
        }
      } else {
        results[ch - startCh].state = STATE_DISCONNECTED;
      }
    }
  }
    // --- SPECIAL CASE: K3A5 disconnected & K3B1 short→A5 ⇒ both connected ---
  {
    const int startCh = 52;           // K3 group mulai di global index 52 (channel 53)
    const int idxA5   = 4;            // offset K3A5: (57−1)−52 = 4
    const int idxB1   = 12;           // offset K3B1: (65−1)−52 = 12
    // Jika A5 putus dan B1 short ke A5
    if ( results[idxA5].state   == STATE_DISCONNECTED
      && results[idxB1].state   == STATE_SHORT
      && results[idxB1].partner == (startCh + idxA5)
    ) {
      // Tanda kedua channel sebagai connected
      results[idxA5].state   = STATE_CONNECTED;
      results[idxB1].state   = STATE_CONNECTED;
      // Clear partner agar tidak tercetak S&... atau W&...
      results[idxA5].partner = -1;
      results[idxB1].partner = -1;
    }
     yield();
  }
  // 5) Cetak hasil untuk K1 saja
  for (int i = startCh; i < endCh; i++) {
    String label = getLabel(i+1);
    String s;
    ChannelResult &r = results[i - startCh];
    switch (r.state) {
      case STATE_CONNECTED:    s = "C"; break;
      case STATE_DISCONNECTED: s = "N"; break;
      case STATE_SHORT:
        s = "S&" + getLabel(r.partner+1).substring(getLabel(r.partner+1).indexOf('-')+1);
        break;
      case STATE_MISWIRE:
        s = "W&" + getLabel(r.partner+1).substring(getLabel(r.partner+1).indexOf('-')+1);
        break;
      default: s = "E"; break;
    }
    char buf[40];
snprintf(buf, sizeof(buf), "%s:%s,", label.c_str(), s.c_str());
    outputBuffer += buf;
    yield();
  }
}


// ===================================================
// Run QC untuk 8 channel “X” (MUX6),
// dengan deteksi antar-MUX (tetap pada 88 global)
// ===================================================
void runQCX(String &outputBuffer) {
  struct ChannelResult { int state, partner; };
  ChannelResult resultsX[8];

  for (int i = 0; i < 8; i++) {
    resultsX[i].state   = -1;
    resultsX[i].partner = -1;
  }

  for (int lx = 0; lx < 8; lx++) {
    int ch = 80 + lx;

    uint8_t buf[11] = {0};
    buf[ch/8] = 1 << (ch % 8);
    shiftOut88(buf);
    delayMicroseconds(5);

    bool globalMap[88] = {0};
    // MUX1–5
    for (int m = 1; m <= 5; m++) {
      uint16_t d16 = readMux16(m);
      for (int b = 0; b < 16; b++) {
        globalMap[(m-1)*16 + b] = (d16 >> b) & 1;
      }
    }
    // MUX6
    uint16_t dx = readMux16X();
    for (int b = 0; b < 8; b++) {
      globalMap[80 + b] = (dx >> b) & 1;
    }

    // 3) Hitung total & selfActive
    int totalActive = 0;
    for (int i = 0; i < 88; i++) totalActive += globalMap[i];
    bool selfActive = globalMap[ch];

    // 4) Tentukan state & partner
    if (selfActive) {
      if (totalActive == 1) {
        resultsX[lx].state = STATE_CONNECTED;
      } else {
        resultsX[lx].state = STATE_SHORT;
        for (int i = 0; i < 88; i++) {
          if (i != ch && globalMap[i]) {
            resultsX[lx].partner = i;
            break;
          }
        }
      }
    } else {
      if (totalActive > 0) {
        resultsX[lx].state = STATE_MISWIRE;
        for (int i = 0; i < 88; i++) {
          if (globalMap[i]) {
            resultsX[lx].partner = i;
            break;
          }
        }
      } else {
        resultsX[lx].state = STATE_DISCONNECTED;
      }
    }
  }

  // 5) Cetak hasil X
  for (int lx = 0; lx < 8; lx++) {
    int ch = 80 + lx;
    String label = getLabelX(lx);
    String s;
    switch (resultsX[lx].state) {
      case STATE_CONNECTED:    s = "C"; break;
      case STATE_DISCONNECTED: s = "N"; break;
      case STATE_SHORT: {
        int p = resultsX[lx].partner;
        String pl = (p < 80) ? getLabel(p+1) : getLabelX(p-80);
        s = "S&" + pl.substring(pl.indexOf('-')+1);
        break;
      }
      case STATE_MISWIRE: {
        int p = resultsX[lx].partner;
        String pl = (p < 80) ? getLabel(p+1) : getLabelX(p-80);
        s = "W&" + pl.substring(pl.indexOf('-')+1);
        break;
      }
      default: s = "E"; break;
    }
    char buf[40];
snprintf(buf, sizeof(buf), "%s:%s,", label.c_str(), s.c_str());
    outputBuffer += buf;
    yield();
  }
}



//
// Fungsi shift register untuk 88 bit (untuk kabel X)
// menggunakan array 11 byte
//
void shiftOut88(uint8_t data[11]) {
  digitalWrite(STCP, LOW);
  for (int i = 87; i >= 0; i--) {
    digitalWrite(SHCP, LOW);
    int byteIndex = i / 8;     
    int bitIndex = i % 8;
    uint8_t bitVal = (data[byteIndex] >> bitIndex) & 1;
    digitalWrite(DS, bitVal);
    digitalWrite(SHCP, HIGH);
    delayMicroseconds(10);
  }
  digitalWrite(STCP, HIGH);
  delayMicroseconds(20);
}

// Membaca MUX 6 untuk kabel X
uint16_t readMux16X() {
  uint16_t muxData = 0;
  // Pastikan MUX lainnya non-aktif
  digitalWrite(EN_MUX1, HIGH);
  digitalWrite(EN_MUX2, HIGH);
  digitalWrite(EN_MUX3, HIGH);
  digitalWrite(EN_MUX4, HIGH);
  digitalWrite(EN_MUX5, HIGH);
  // Aktifkan MUX 6
  digitalWrite(EN_MUX6, LOW);
  
  for (int i = 0; i < 16; i++) {
    digitalWrite(S0, i & 0x01);
    digitalWrite(S1, (i >> 1) & 0x01);
    digitalWrite(S2, (i >> 2) & 0x01);
    digitalWrite(S3, (i >> 3) & 0x01);
    delayMicroseconds(10);
    
    pinMode(SIG, INPUT_PULLDOWN);
    int val = digitalRead(SIG);
    if (val == HIGH) {
      muxData |= (1 << i);
    }
  }
  return muxData;
}

// Menghasilkan label untuk kabel X (X1 sampai X8)
String getLabelX(int localChannel) {
  return "X-" + String(localChannel + 1);
}

//
// Fungsi runQCX() untuk kabel X (channel 80-87)
// tanpa sampling iteratif (mengambil pembacaan satu kali)
//
//
// Setup dan Loop utama
//
void setup() {
  pinMode(DS, OUTPUT);
  pinMode(SHCP, OUTPUT);
  pinMode(STCP, OUTPUT);
  
  pinMode(SIG, INPUT_PULLDOWN);
  
  pinMode(S0, OUTPUT);
  pinMode(S1, OUTPUT);
  pinMode(S2, OUTPUT);
  pinMode(S3, OUTPUT);
  pinMode(EN_MUX1, OUTPUT);
  pinMode(EN_MUX2, OUTPUT);
  pinMode(EN_MUX3, OUTPUT);
  pinMode(EN_MUX4, OUTPUT);
  pinMode(EN_MUX5, OUTPUT);
  pinMode(EN_MUX6, OUTPUT);  
  
  digitalWrite(EN_MUX1, LOW);
  digitalWrite(EN_MUX2, LOW);
  digitalWrite(EN_MUX3, LOW);
  digitalWrite(EN_MUX4, LOW);
  digitalWrite(EN_MUX5, LOW);
  digitalWrite(EN_MUX6, HIGH); 

  Serial.begin(115200);
  SerialBT.begin("QC Cable");
  delay(1000);                       
}

bool qcRunning   = false;       
unsigned long lastQC     = 0;    
const unsigned long qcInterval = 10;  

void loop() {
  static String bufUSB = "";
  static String bufBT  = "";


  while (Serial.available()) {
    char c = Serial.read();
    bufUSB += c;
  }

  while (SerialBT.available()) {
    char c = SerialBT.read();
    bufBT += c;
  }

  if ( bufUSB.indexOf("startall") >= 0 || bufBT.indexOf("startall") >= 0 ) {
    qcRunning   = true;
    qcAllActive = true;
    qcActive    = false;
    qcActiveX   = false;
    bufUSB = ""; 
    bufBT  = "";
  }
  else if ( bufUSB.indexOf("startx")   >= 0 || bufBT.indexOf("startx")   >= 0 ) {
    qcRunning   = true;
    qcActiveX   = true;
    qcActive    = false;
    qcAllActive = false;
    bufUSB = "";
    bufBT  = "";
  }
  else if ( bufUSB.indexOf("start")    >= 0 || bufBT.indexOf("start")    >= 0 ) {
    qcRunning   = true;
    qcActive    = true;
    qcAllActive = false;
    qcActiveX   = false;
    bufUSB = "";
    bufBT  = "";
  }
  else if ( bufUSB.indexOf("stop")     >= 0 || bufBT.indexOf("stop")     >= 0 ) {
    qcRunning   = false;
    qcAllActive = qcActive = qcActiveX = false;
    resetPins();
    bufUSB = "";
    bufBT  = "";
  }


  if (qcRunning) {
    unsigned long now = millis();
    if (now - lastQC >= qcInterval) {
      lastQC = now;

      String out = "";
      if (qcAllActive || qcActive) {
        runQC_K1(out);
        runQC_K2(out);
        runQC_K3(out);
      }
      if (qcAllActive || qcActiveX) {
        digitalWrite(EN_MUX6, LOW);
        runQCX(out);
        digitalWrite(EN_MUX6, HIGH);
      }
      Serial.println(out);
      SerialBT.println(out);
    }
  }
}

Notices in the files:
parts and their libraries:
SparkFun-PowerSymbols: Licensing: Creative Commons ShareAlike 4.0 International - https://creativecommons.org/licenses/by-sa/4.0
